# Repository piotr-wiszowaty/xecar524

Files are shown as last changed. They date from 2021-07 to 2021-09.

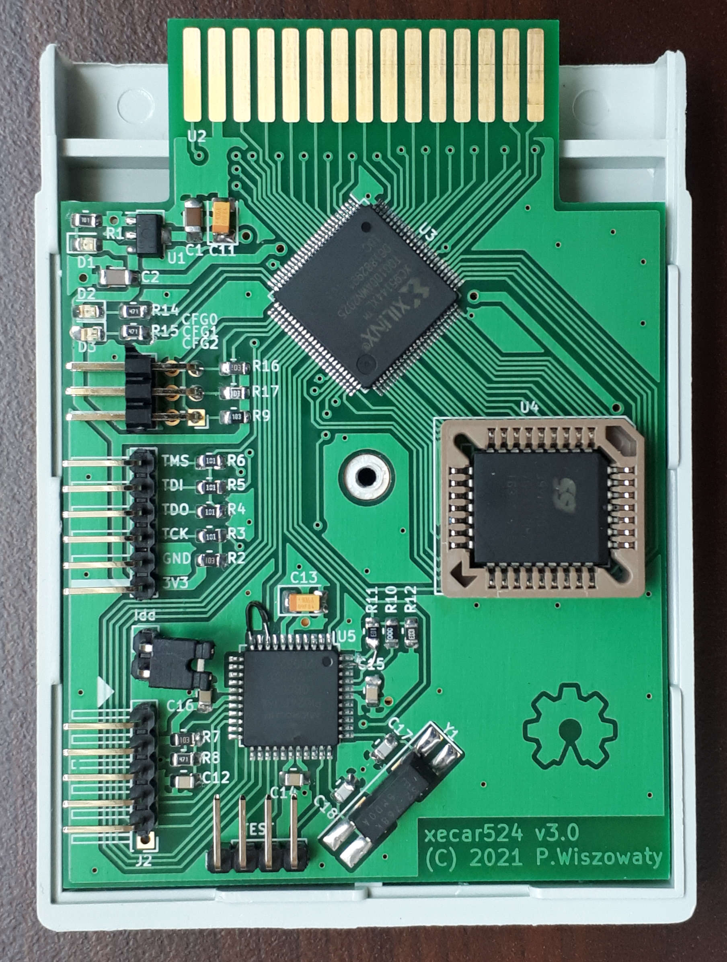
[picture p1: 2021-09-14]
pics/xecar524-v3.0-top.jpg

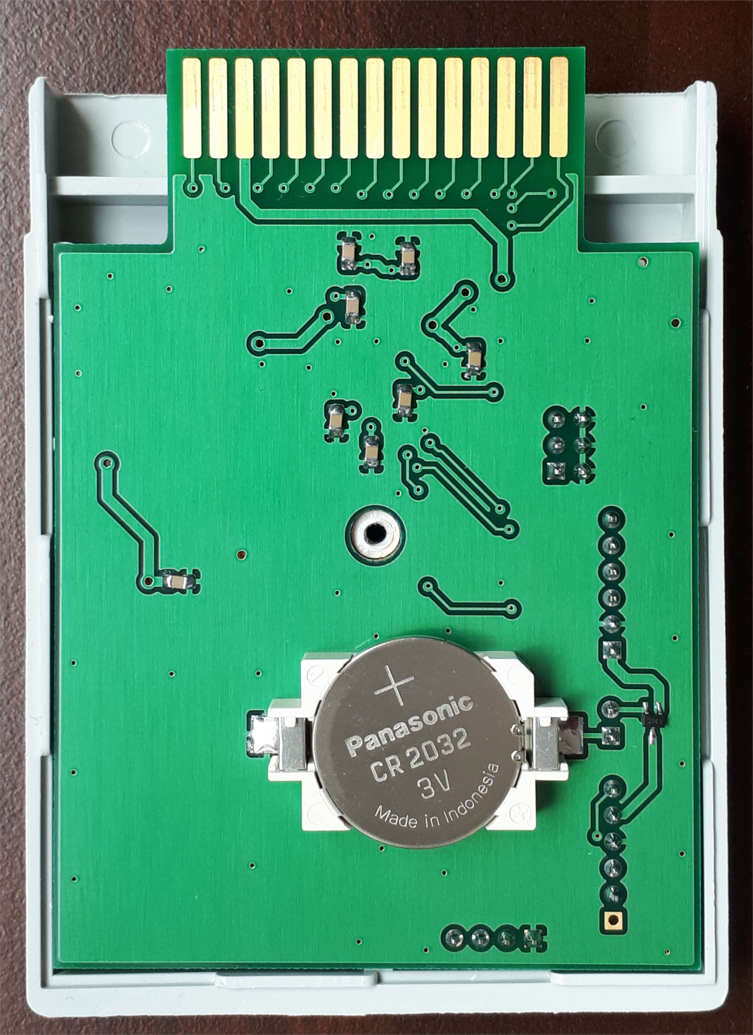
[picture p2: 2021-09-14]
pics/xecar524-v3.0-bottom.jpg

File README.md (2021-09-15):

xecar524
========

An [Atari XL/XE](http://en.wikipedia.org/wiki/Atari_8-bit_family) flash cartridge
with a battery backed up R-Time 8 emulator. The device handles up to 4 Mbit,
3.3V, PLCC-32 flash memories (e.g. SST39VF010, SST39VF020, SST39VF040).

By default the base SDX image at `$00000` is loaded. Another cartridge image
may be switched to by using `CAR` command.

ROM Memory Map
--------------

* `$00000`..`$1FFFF` - SpartaDOS X 4.49, 128k (SDX449\_sdx128.rom)
* `$20000`..`$23FFF` - 043M OSS cartridge (e.g. MAC/65 1.00)
* `$24000`..`$27FFF` - 034M OSS cartridge (e.g. MAC-65 v1.02)
* `$28000`..`$2BFFF` - standard 16k cartridge
* `$2C000`..`$2DFFF` - standard 8k cartridge

Cartridge Selection
-------------------

The cartridge image to switch to is selected with jumpers:

* `CFG0`: off, `CFG1`: off - 043M OSS cartridge
* `CFG0`: on,  `CFG1`: off - 034M OSS cartridge
* `CFG0`: off, `CFG1`: on  - standard 16k cartridge
* `CFG0`: on,  `CFG1`: on  - standard 8k cartridge

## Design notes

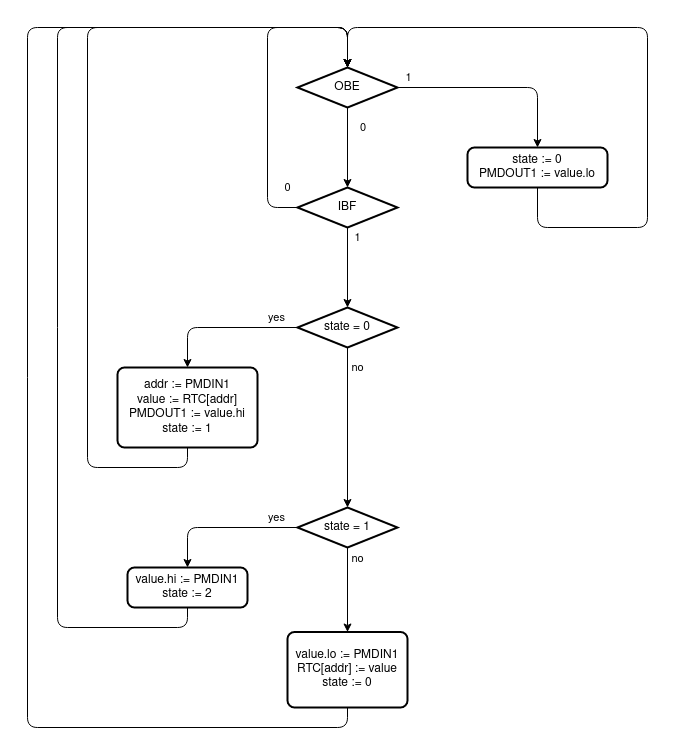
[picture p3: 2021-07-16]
rtime8_emu/rtime8_emu.png

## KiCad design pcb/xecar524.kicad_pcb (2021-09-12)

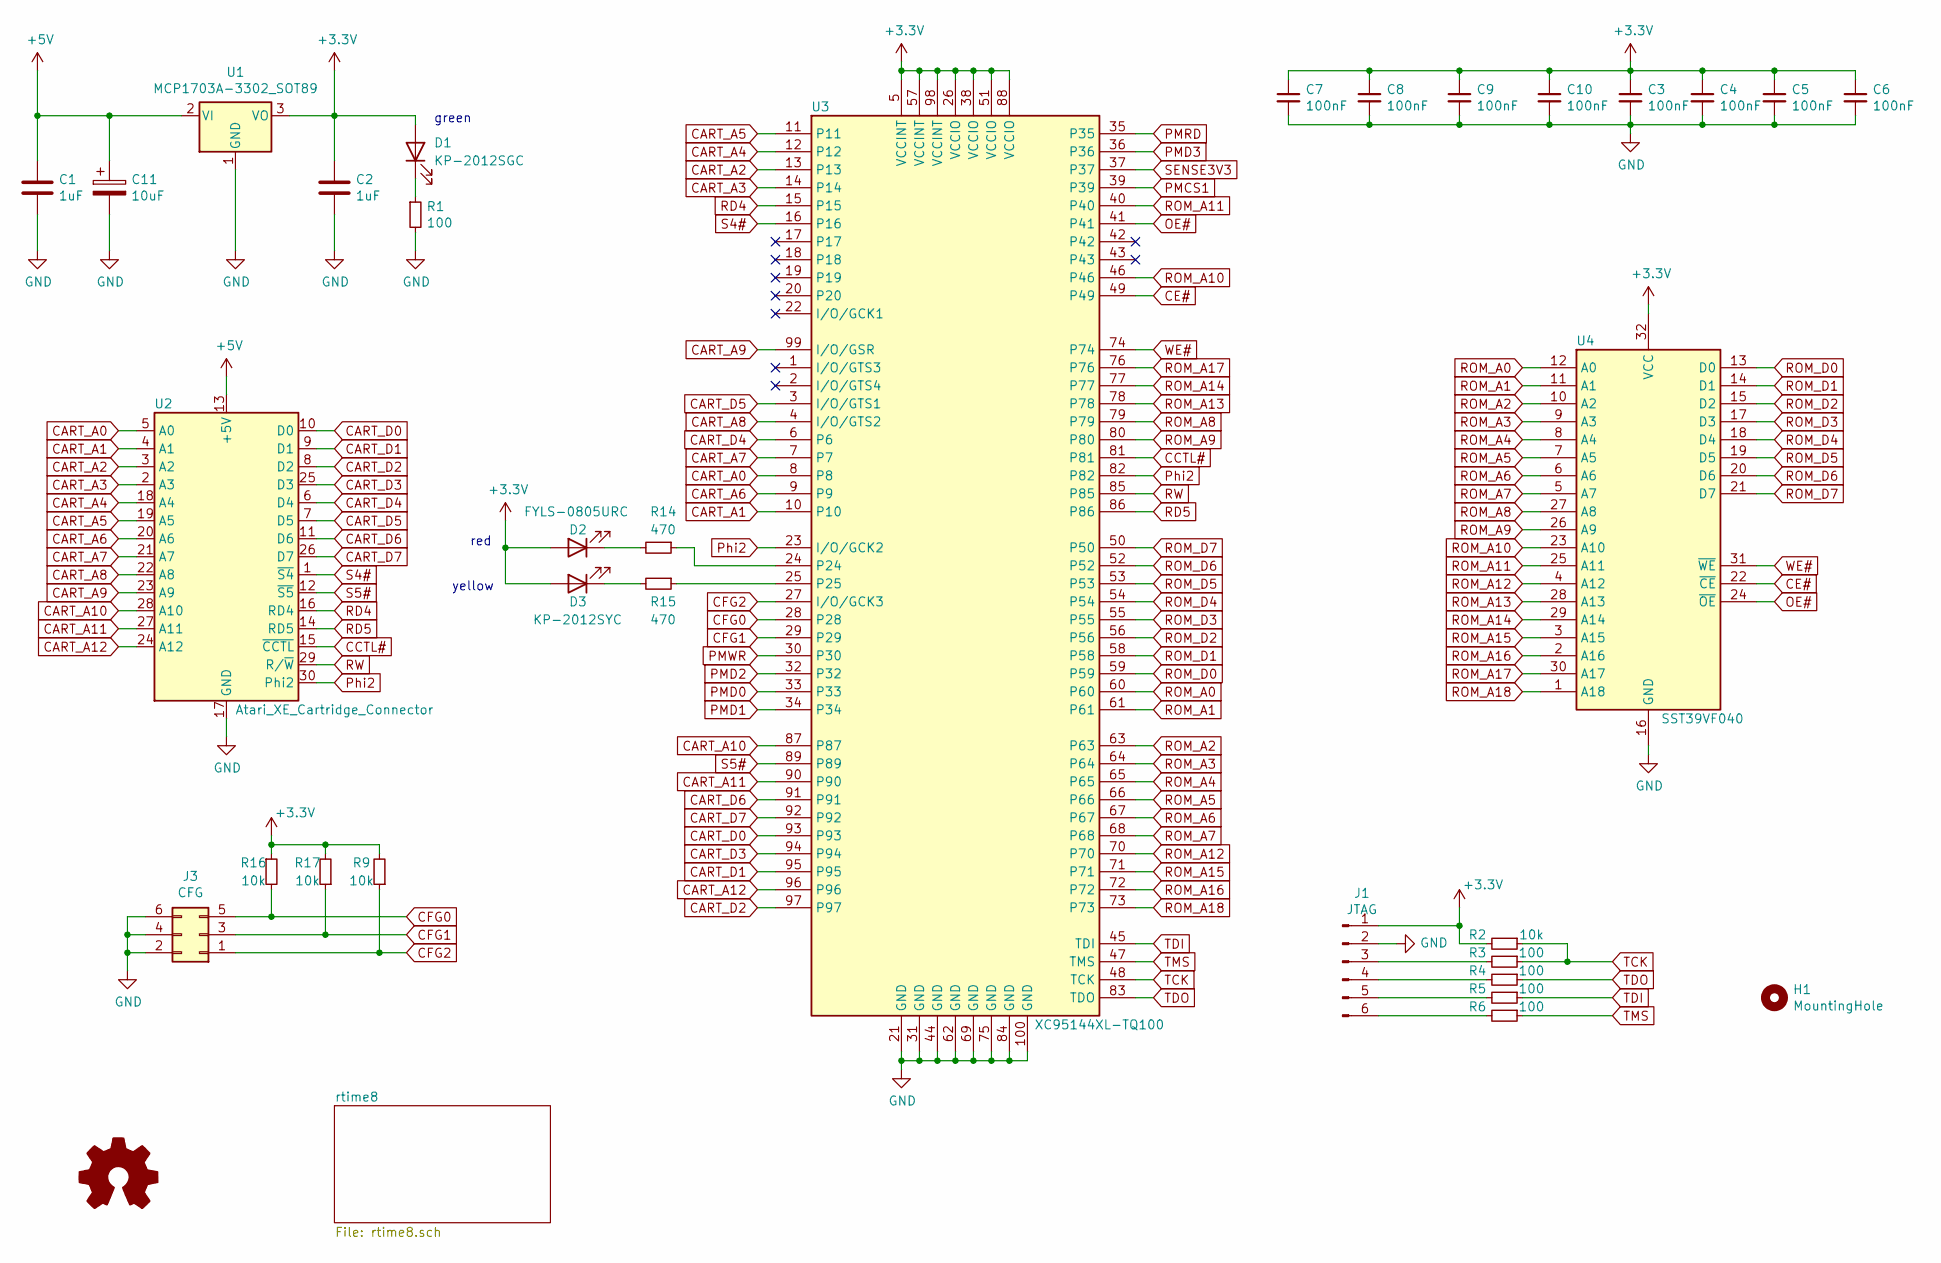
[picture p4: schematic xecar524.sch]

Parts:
C1, C2: 1uF; C_1206_3216Metric_Pad1.33x1.80mm_HandSolder
C3, C4, C5, C6, C7, C8, C9, C10: 100nF; C_0805_2012Metric_Pad1.18x1.45mm_HandSolder
C11: 10uF; CP_EIA-3528-12_Kemet-T_Pad1.50x2.35mm_HandSolder
D1: KP-2012SGC; D_0805_2012Metric_Pad1.15x1.40mm_HandSolder
D2: FYLS-0805URC; D_0805_2012Metric_Pad1.15x1.40mm_HandSolder
D3: KP-2012SYC; D_0805_2012Metric_Pad1.15x1.40mm_HandSolder
H1: MountingHole; MountingHole_5mm
J1: JTAG; PinHeader_1x06_P2.54mm_Horizontal_HighProfile
J3: CFG; PinHeader_2x03_P2.54mm_Horizontal
LOGO1: Logo_Open_Hardware_Small; OSHW-Symbol_8.9x8mm_Copper
R1, R3, R4, R5, R6: 100; R_0805_2012Metric_Pad1.20x1.40mm_HandSolder
R2, R9, R16, R17: 10k; R_0805_2012Metric_Pad1.20x1.40mm_HandSolder
R14, R15: 470; R_0805_2012Metric_Pad1.20x1.40mm_HandSolder
U1: MCP1703A-3302_SOT89; SOT-89-3
U2: Atari_XE_Cartridge_Connector
U3: XC95144XL-TQ100; TQFP-100_14x14mm_P0.5mm
U4: SST39VF040; PLCC-32_SMD-Socket

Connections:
+3V3: C2.1, C3.1, C4.1, C5.1, C6.1, C7.1, C8.1, C9.1, C10.1, D1.2 (A), D2.2 (A), D3.2 (A), J1.1, R2.2, R9.2, R16.1, R17.2, U1.3 (VO), U3.5 (VCCINT), U3.26 (VCCIO), U3.38 (VCCIO), U3.51 (VCCIO), U3.57 (VCCINT), U3.88 (VCCIO), U3.98 (VCCINT), U4.32 (VCC); also elsewhere on the board
+5V: C1.1, C11.1, U1.2 (VI), U2.13 (+5V)
CART_A0: U2.5 (A0), U3.8
CART_A1: U2.4 (A1), U3.10
CART_A2: U2.3 (A2), U3.13
CART_A3: U2.2 (A3), U3.14
CART_A4: U2.18 (A4), U3.12
CART_A5: U2.19 (A5), U3.11
CART_A6: U2.20 (A6), U3.9
CART_A7: U2.21 (A7), U3.7
CART_A8: U2.22 (A8), U3.4 (I/O/GTS2)
CART_A9: U2.23 (A9), U3.99 (I/O/GSR)
CART_A10: U2.28 (A10), U3.87
CART_A11: U2.27 (A11), U3.90
CART_A12: U2.24 (A12), U3.96
CART_D0: U2.10 (D0), U3.93
CART_D1: U2.9 (D1), U3.95
CART_D2: U2.8 (D2), U3.97
CART_D3: U2.25 (D3), U3.94
CART_D4: U2.6 (D4), U3.6
CART_D5: U2.7 (D5), U3.3 (I/O/GTS1)
CART_D6: U2.11 (D6), U3.91
CART_D7: U2.26 (D7), U3.92
CCTL#: U2.15 (~CCTL~), U3.81
CE#: U3.49, U4.22 (~CE~)
CFG0: J3.5, R16.2, U3.28
CFG1: J3.3, R17.1, U3.29
CFG2: J3.1, R9.1, U3.27 (I/O/GCK3)
GND: C1.2, C2.2, C3.2, C4.2, C5.2, C6.2, C7.2, C8.2, C9.2, C10.2, C11.2, J1.2, J3.2, J3.4, J3.6, R1.2, U1.1 (GND), U2.17 (GND), U3.21 (GND), U3.31 (GND), U3.44 (GND), U3.62 (GND), U3.69 (GND), U3.75 (GND), U3.84 (GND), U3.100 (GND), U4.16 (GND); also elsewhere on the board
unnamed: D1.1 (K), R1.1
unnamed: D2.1 (K), R14.2
unnamed: D3.1 (K), R15.2
unnamed: J1.3, R3.2
unnamed: J1.4, R4.2
unnamed: J1.5, R5.2
unnamed: J1.6, R6.2
unnamed: R14.1, U3.24
unnamed: R15.1, U3.25
OE#: U3.41, U4.24 (~OE~)
PMCS1: U3.39; also elsewhere on the board
PMD0: U3.33; also elsewhere on the board
PMD1: U3.34; also elsewhere on the board
PMD2: U3.32; also elsewhere on the board
PMD3: U3.36; also elsewhere on the board
PMRD: U3.35; also elsewhere on the board
PMWR: U3.30; also elsewhere on the board
Phi2: U2.30 (Phi2), U3.23 (I/O/GCK2), U3.82
RD4: U2.16 (RD4), U3.15
RD5: U2.14 (RD5), U3.86
ROM_A0: U3.60, U4.12 (A0)
ROM_A1: U3.61, U4.11 (A1)
ROM_A2: U3.63, U4.10 (A2)
ROM_A3: U3.64, U4.9 (A3)
ROM_A4: U3.65, U4.8 (A4)
ROM_A5: U3.66, U4.7 (A5)
ROM_A6: U3.67, U4.6 (A6)
ROM_A7: U3.68, U4.5 (A7)
ROM_A8: U3.79, U4.27 (A8)
ROM_A9: U3.80, U4.26 (A9)
ROM_A10: U3.46, U4.23 (A10)
ROM_A11: U3.40, U4.25 (A11)
ROM_A12: U3.70, U4.4 (A12)
ROM_A13: U3.78, U4.28 (A13)
ROM_A14: U3.77, U4.29 (A14)
ROM_A15: U3.71, U4.3 (A15)
ROM_A16: U3.72, U4.2 (A16)
ROM_A17: U3.76, U4.30 (A17)
ROM_A18: U3.73, U4.1 (A18)
ROM_D0: U3.59, U4.13 (D0)
ROM_D1: U3.58, U4.14 (D1)
ROM_D2: U3.56, U4.15 (D2)
ROM_D3: U3.55, U4.17 (D3)
ROM_D4: U3.54, U4.18 (D4)
ROM_D5: U3.53, U4.19 (D5)
ROM_D6: U3.52, U4.20 (D6)
ROM_D7: U3.50, U4.21 (D7)
RW: U2.29 (R/~W~), U3.85
S4#: U2.1 (~S4~), U3.16
S5#: U2.12 (~S5~), U3.89
SENSE3V3: U3.37; also elsewhere on the board
TCK: R2.1, R3.1, U3.48 (TCK)
TDI: R5.1, U3.45 (TDI)
TDO: R4.1, U3.83 (TDO)
TMS: R6.1, U3.47 (TMS)
WE#: U3.74, U4.31 (~WE~)

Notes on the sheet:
green
red
yellow

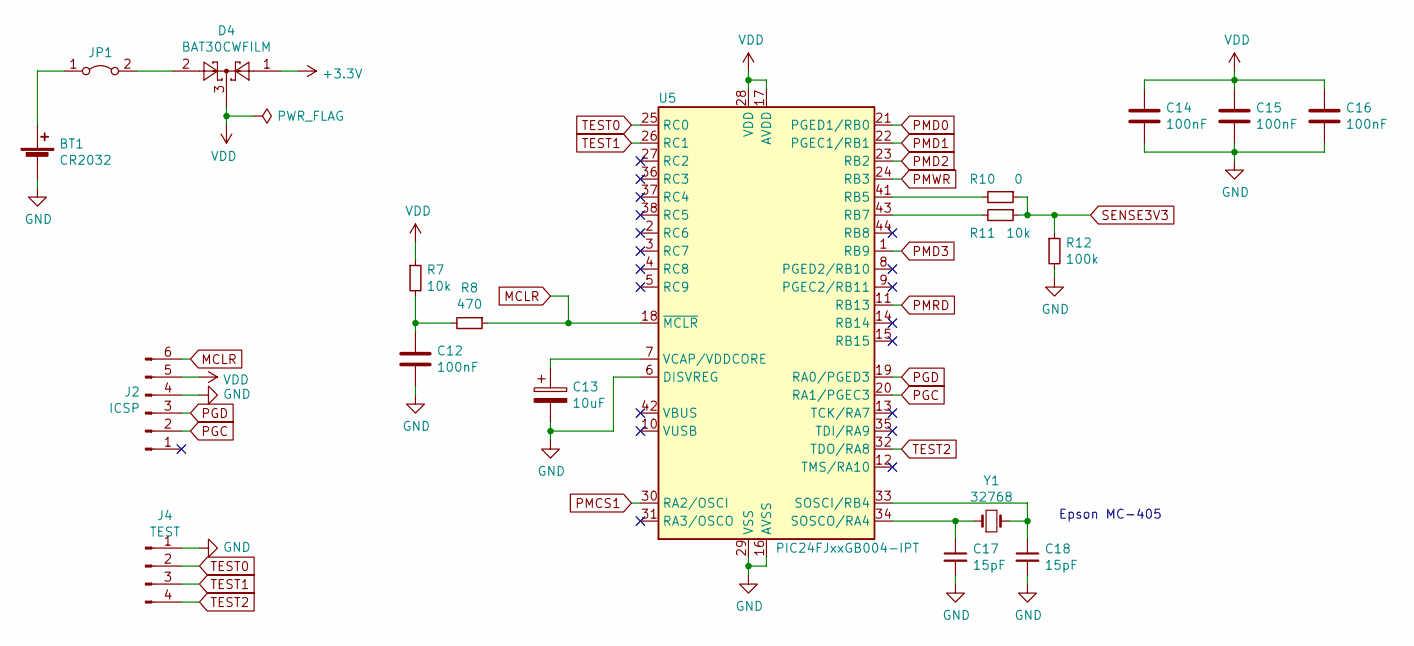
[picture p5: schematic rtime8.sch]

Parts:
BT1: CR2032; BatteryHolder_Connfly_DS1092-10
C12, C14, C15, C16: 100nF; C_0805_2012Metric_Pad1.18x1.45mm_HandSolder
C13: 10uF; CP_EIA-3528-12_Kemet-T_Pad1.50x2.35mm_HandSolder
C17, C18: 15pF; C_0805_2012Metric_Pad1.18x1.45mm_HandSolder
D4: BAT30CWFILM; SOT-323_SC-70_Handsoldering
J2: ICSP; PinHeader_1x06_P2.54mm_Horizontal_HighProfile
J4: TEST; PinHeader_1x04_P2.54mm_Vertical
JP1: Jumper_2_Bridged; PinHeader_1x02_P2.54mm_Vertical
R7, R11: 10k; R_0805_2012Metric_Pad1.20x1.40mm_HandSolder
R8: 470; R_0805_2012Metric_Pad1.20x1.40mm_HandSolder
R10: 0; R_0805_2012Metric_Pad1.20x1.40mm_HandSolder
R12: 100k; R_0805_2012Metric_Pad1.20x1.40mm_HandSolder
U5: PIC24FJxxGB004-IPT; TQFP-44_10x10mm_P0.8mm
Y1: 32768; Crystal_SMD_SeikoEpson_MC406-4Pin_9.6x4.1mm_HandSoldering

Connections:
+3V3: D4.1; also elsewhere on the board
GND: BT1.2 (-), C12.2, C13.2, C14.2, C15.2, C16.2, C17.2, C18.2, J2.4, J4.1, R12.2, U5.6 (DISVREG), U5.16 (AVSS), U5.29 (VSS), U5.39 (VSS); also elsewhere on the board
MCLR: J2.6, R8.1, U5.18 (~MCLR~)
unnamed: BT1.1 (+), JP1.1 (A)
unnamed: C12.1, R7.2, R8.2
unnamed: C13.1, U5.7 (VCAP/VDDCORE)
unnamed: C17.1, U5.34 (SOSCO/RA4), Y1.1, Y1.4
unnamed: C18.1, U5.33 (SOSCI/RB4), Y1.2, Y1.3
unnamed: D4.2, JP1.2 (B)
unnamed: R10.2, U5.41 (RB5)
unnamed: R11.2, U5.43 (RB7)
PGC: J2.2, U5.20 (RA1/PGEC3)
PGD: J2.3, U5.19 (RA0/PGED3)
PMCS1: U5.30 (RA2/OSCI); also elsewhere on the board
PMD0: U5.21 (PGED1/RB0); also elsewhere on the board
PMD1: U5.22 (PGEC1/RB1); also elsewhere on the board
PMD2: U5.23 (RB2); also elsewhere on the board
PMD3: U5.1 (RB9); also elsewhere on the board
PMRD: U5.11 (RB13); also elsewhere on the board
PMWR: U5.24 (RB3); also elsewhere on the board
SENSE3V3: R10.1, R11.1, R12.1; also elsewhere on the board
TEST0: J4.2, U5.25 (RC0)
TEST1: J4.3, U5.26 (RC1)
TEST2: J4.4, U5.32 (TDO/RA8)
VDD: C14.1, C15.1, C16.1, D4.3, J2.5, R7.1, U5.17 (AVDD), U5.28 (VDD), U5.40 (VDD)

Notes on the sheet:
Epson MC-405

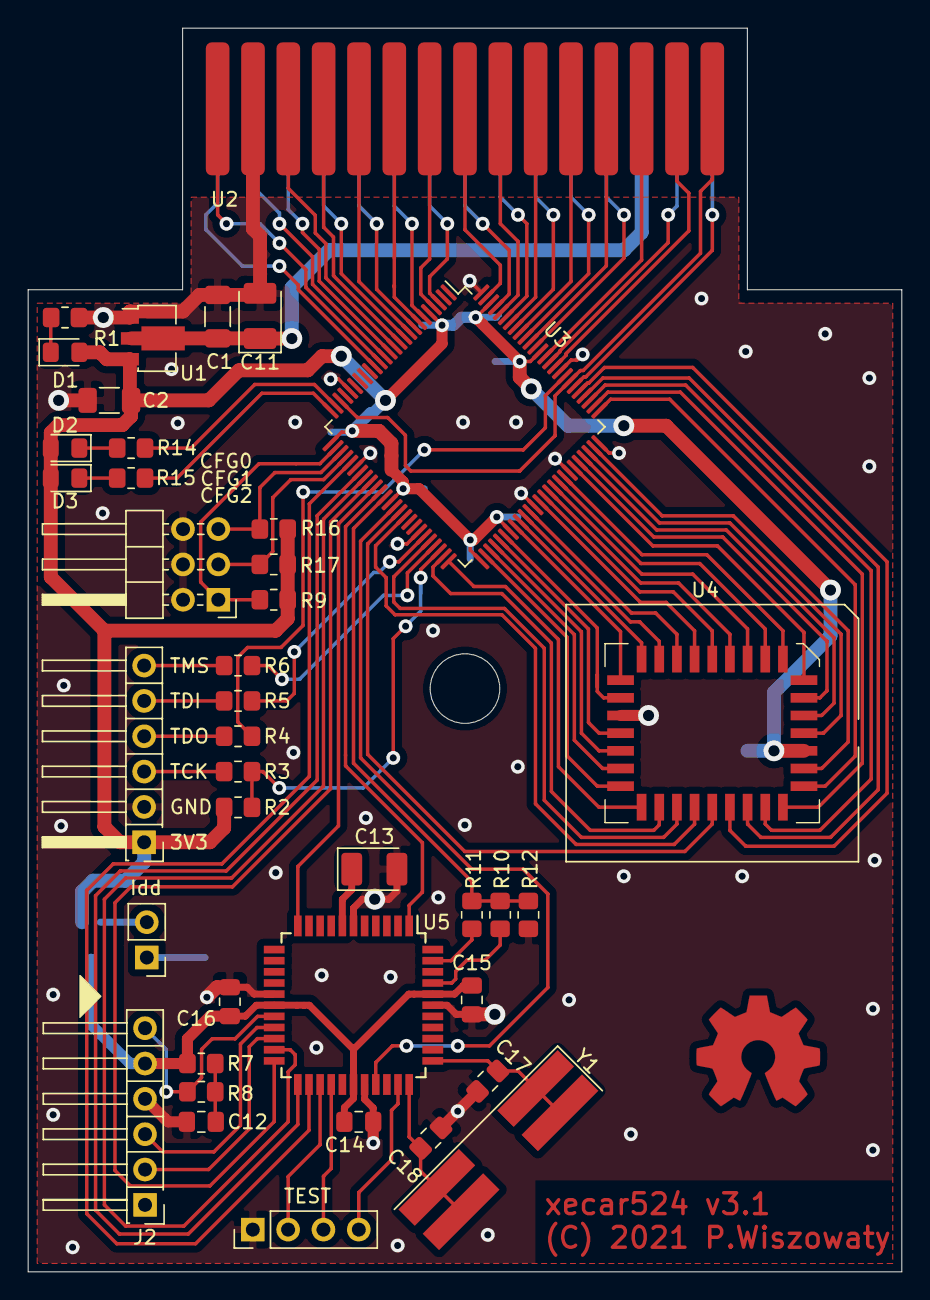
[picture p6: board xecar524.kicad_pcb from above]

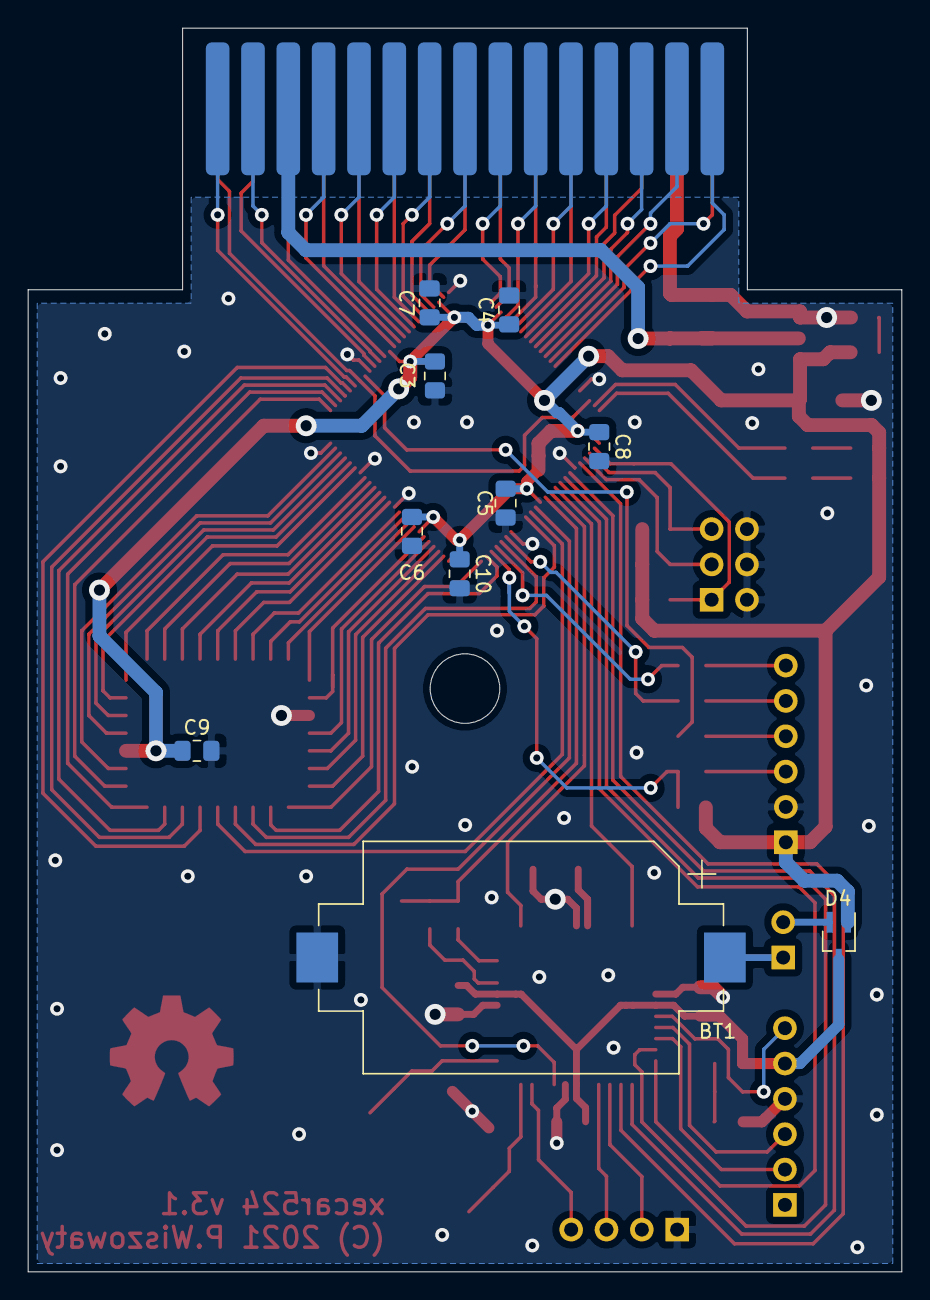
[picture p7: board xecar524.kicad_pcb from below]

Board: 2 copper layers, 62.8 x 89.4 mm, 52 parts (10 on the bottom side), 100 nets.

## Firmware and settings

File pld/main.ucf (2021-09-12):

#NET "phi2" LOC = "P82";
NET "phi2" LOC = "P23";
NET "r_w" LOC = "P85";
NET "rd4" LOC = "P15";
NET "rd5" LOC = "P86";
NET "s4_n" LOC = "P16";
NET "s5_n" LOC = "P89";
NET "cctl_n" LOC = "P81";
NET "cart_d<0>" LOC = "P93";
NET "cart_d<1>" LOC = "P95";
NET "cart_d<2>" LOC = "P97";
NET "cart_d<3>" LOC = "P94";
NET "cart_d<4>" LOC = "P6";
NET "cart_d<5>" LOC = "P3";
NET "cart_d<6>" LOC = "P91";
NET "cart_d<7>" LOC = "P92";
NET "cart_a<0>" LOC = "P8";
NET "cart_a<1>" LOC = "P10";
NET "cart_a<2>" LOC = "P13";
NET "cart_a<3>" LOC = "P14";
NET "cart_a<4>" LOC = "P12";
NET "cart_a<5>" LOC = "P11";
NET "cart_a<6>" LOC = "P9";
NET "cart_a<7>" LOC = "P7";
NET "cart_a<8>" LOC = "P4";
NET "cart_a<9>" LOC = "P99";
NET "cart_a<10>" LOC = "P87";
NET "cart_a<11>" LOC = "P90";
NET "cart_a<12>" LOC = "P96";

NET "we_n" LOC = "P74";
NET "oe_n" LOC = "P41";
NET "ce_n" LOC = "P49";
NET "rom_d<0>" LOC = "P59";
NET "rom_d<1>" LOC = "P58";
NET "rom_d<2>" LOC = "P56";
NET "rom_d<3>" LOC = "P55";
NET "rom_d<4>" LOC = "P54";
NET "rom_d<5>" LOC = "P53";
NET "rom_d<6>" LOC = "P52";
NET "rom_d<7>" LOC = "P50";
NET "rom_a<0>" LOC = "P60";
NET "rom_a<1>" LOC = "P61";
NET "rom_a<2>" LOC = "P63";
NET "rom_a<3>" LOC = "P64";
NET "rom_a<4>" LOC = "P65";
NET "rom_a<5>" LOC = "P66";
NET "rom_a<6>" LOC = "P67";
NET "rom_a<7>" LOC = "P68";
NET "rom_a<8>" LOC = "P79";
NET "rom_a<9>" LOC = "P80";
NET "rom_a<10>" LOC = "P46";
NET "rom_a<11>" LOC = "P40";
NET "rom_a<12>" LOC = "P70";
NET "rom_a<13>" LOC = "P78";
NET "rom_a<14>" LOC = "P77";
NET "rom_a<15>" LOC = "P71";
NET "rom_a<16>" LOC = "P72";
NET "rom_a<17>" LOC = "P76";
NET "rom_a<18>" LOC = "P73";

NET "pmcs1" LOC = "P39";
NET "pmwr" LOC = "P30";
NET "pmrd" LOC = "P35";
NET "pmd<0>" LOC = "P33";
NET "pmd<1>" LOC = "P34";
NET "pmd<2>" LOC = "P32";
NET "pmd<3>" LOC = "P36";
NET "sense3v3" LOC = "P37";

NET "cfg0" LOC = "P28";
NET "cfg1" LOC = "P29";
NET "cfg2" LOC = "P27";

NET "led_r" LOC = "P24";
NET "led_y" LOC = "P25";

NET "phi2" TNM_NET = phi2;
TIMESPEC TS_phi2 = PERIOD "phi2" 562 ns HIGH 250 ns;

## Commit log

2021-06-13 Add PCB design files
    [xecar524.kicad_pcb, xecar524.sch]
2021-06-13 PCB: Add top GND copper pour
    [xecar524.kicad_pcb]
2021-06-13 PCB: Tweak some tracks
    [xecar524.kicad_pcb]
2021-06-13 PCB: Tweak tracks
    [xecar524.kicad_pcb]
2021-06-13 PCB: Tweak electrical schematic
    [xecar524.sch]
2021-06-14 PCB: Add CAM files
    [xecar524-B_Cu.gbr, xecar524-B_Mask.gbr, xecar524-Edge_Cuts.gbr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]
2021-06-17 PCB: Tweak one track
    [xecar524.kicad_pcb]
2021-06-29 PCB: Widen some power tracks
    [xecar524.kicad_pcb]
2021-06-29 PCB: Shrink cartridge connector
    [xecar524.kicad_pcb]
2021-07-04 PCB: Update LEDs and their current-setting resistors
    [xecar524.sch]
2021-07-04 PCB: Exchange cfg signals
    [xecar524.kicad_pcb, xecar524.sch]
2021-07-04 PCB: Decrease yellow LED brightness
    [xecar524.sch]
2021-07-07 PCB: Resize
    [xecar524.kicad_pcb]
2021-07-11 PLD: Turn on message filtering
2021-07-17 PCB, PLD: Integrate R-Time 8 emulator
    [rtime8.sch, xecar524.kicad_pcb, xecar524.sch]
2021-07-17 PCB: Add connector for measuring deep sleep current
    [rtime8.sch, xecar524.kicad_pcb]
2021-07-17 PCB: Add description to deep sleep current measurement connector, add OSHW symbol
    [xecar524.kicad_pcb]
2021-07-17 PCB: Move ICSP connector marker
    [xecar524.kicad_pcb]
2021-07-17 PCB: Add OSHW symbol on schematic
    [xecar524.kicad_pcb, xecar524.sch]
2021-07-17 PCB: Enlarge a GND via
    [xecar524.kicad_pcb]
2021-07-17 PCB: Add test connector
    [rtime8.sch, xecar524.kicad_pcb]
2021-07-17 PCB: Add quartz crystal description
    [rtime8.sch]
2021-07-17 PCB: Move description
    [xecar524.kicad_pcb]
2021-07-18 PCB, PLD: Add one configuration jumper
    [xecar524.kicad_pcb, xecar524.sch]
2021-07-18 PLD: Remove redundant pin constraint
2021-07-18 PCB, PLD: Add a connection between PLD and microcontroller
    [xecar524.kicad_pcb, xecar524.sch]
2021-07-18 Tweak connections between PLD and uC
    [rtime8.sch, xecar524.kicad_pcb, xecar524.sch]
2021-08-10 PCB: Add connection for detecting power loss
    [rtime8.sch, xecar524.kicad_pcb]
2021-08-13 PLD: Update pin assignments
2021-09-12 Switch to PIC24FJ64GB004 as RTime8 emulator
    [rtime8.sch, xecar524.kicad_pcb, xecar524.sch]
2021-09-12 PCB: Update CAM files
    [xecar524-B_Cu.gbr, xecar524-B_Mask.gbr, xecar524-Edge_Cuts.gbr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]
2021-09-14 PCB: Add photos of the device
2021-09-14 PCB: Correct file name

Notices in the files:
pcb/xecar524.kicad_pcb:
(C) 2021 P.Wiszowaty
